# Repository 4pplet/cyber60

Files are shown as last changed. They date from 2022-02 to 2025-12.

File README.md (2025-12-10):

# cyber60

A DIY-friendly 60% using nRF52840 and ZMK: the cyber.

Verified compatibility list: [Link](./COMPAT.md)

## Note:
ALPS and SMK version of revision E are still untested and set as a pre-release. These should work, but I recommend using revision D until the design is fully verified and tested. 

## Availability:
As an option to DIY, I'll try and keep these available for purchase here: https://4pplet.com/ For DIY, the production files are avaliable in releases.

## Software:
- Link to zmk-fork: https://github.com/4pplet/zmk
- Link to zmk-config (uf2-files in actions): https://github.com/4pplet/zmk-config-4pplet

## Instructions:
- How to flash/update bootloader (this is needed to be able to flash firmware via USB): [Link](./instructions/BL_FLASH_INSTRUCTION.md)
- How to flash/update firmware using ZMK-config: [Link](./instructions/ZMK-config_steps.md)
- How to flash/update firmware using ZMK-repo (most difficult): [Link](./instructions/ZMK_steps.md)

Easiest for remapping is to use ZMK Studio: https://zmk.studio/ This requires no reflashing if you already use the latest default firmware.

## Specs cyber60:
- Module: Holyiot YJ-18010 for rev A-D, E73-2G4M08S1C for rev E
- Standard Tray Mount support (need battery cutout for internal battery)
- "rubber worm"-mount support (both bakeneko v1 and bakeneko v3). Case still need battery cutout or space for an internal battery.
- Lipo charger for single cell 3.7V li-po/li-ion batteries (recommended JST SH battery: https://www.upgradekeyboards.com/product/filament-power-batteries-ultra-thin-lipo/, if soldering JST PH, adafruit batteries work well, but make sure they are not too thick)
- RGB-led under Capslock for multi function indicator, not supported on SMK-version. (compatible led for rev A-D: https://www.aliexpress.com/item/1005003719602946.html)
- Four versions running the same FW-implementation. One MX, one MXHS, one ALPS, one SMK
- USB horizontal placement is classic GH60, same as GH60, plain60, voyager60 etc.
- (rev B and newer) Underglow for cozy glow
- (rev B and newer) Buzzer for indicator or sweet tunes
- (rev B and newer) Rotary encoder at right most posision in split backspace or off board (compatible encoder: https://www.aliexpress.com/item/1005001265188249.html)
- (rev B and newer) Reverse polarity protection for battery
- (rev E and newer) Arbitrary battery polarity

## Todo:
- Test and verify ALPS and SMK E1 release.
- Improve flash/update ZMK instruction and documentation.
- Improve ZMK Studio implementation.

# Layout support (non hotswap):
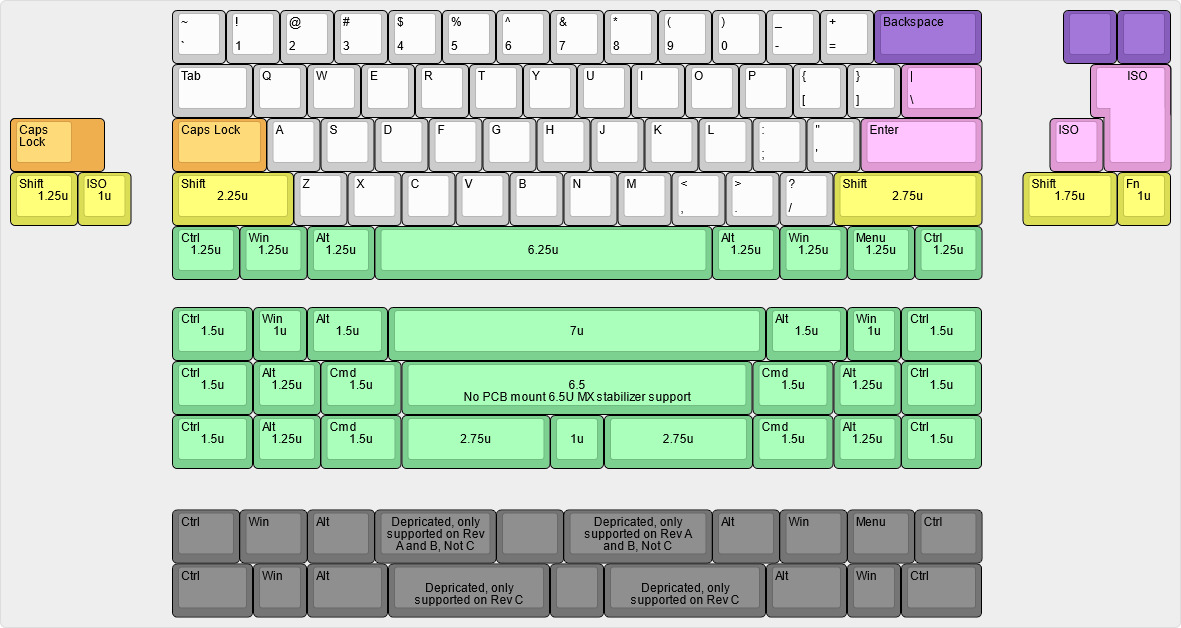
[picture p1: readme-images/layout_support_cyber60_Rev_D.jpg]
Layout support


# MX-version:
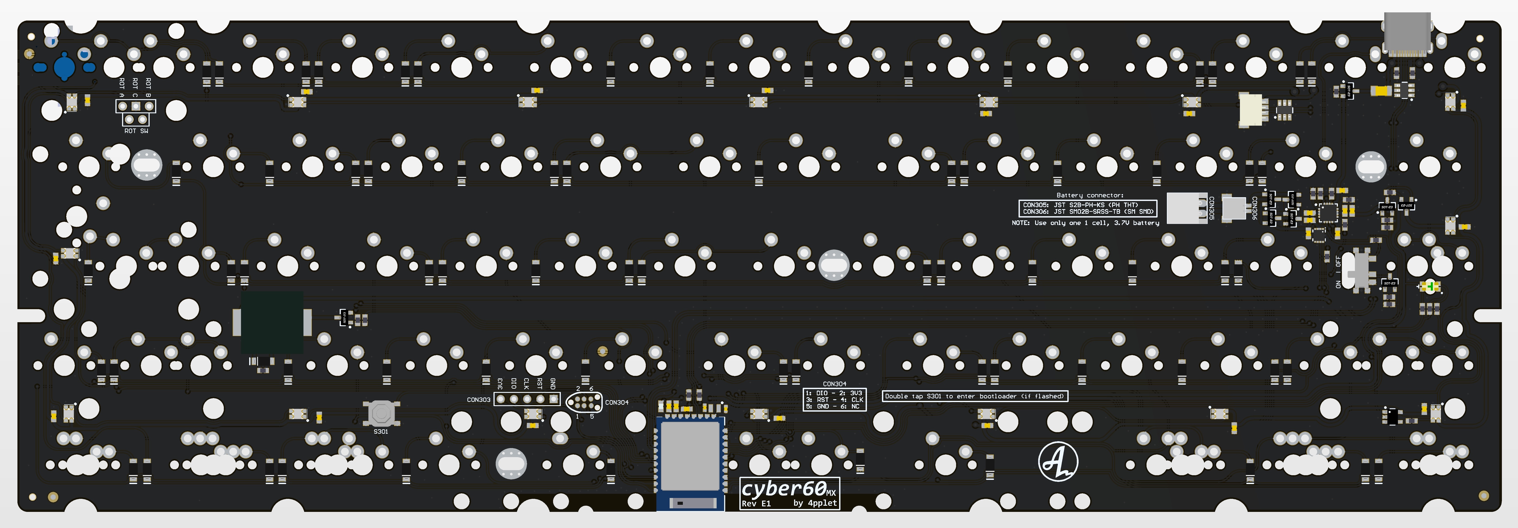
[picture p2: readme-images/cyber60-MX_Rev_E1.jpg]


## MX Revisions:
- A1 - initial revision/prototype
- A2 (prerelease) - flipped PMOS-transistor error in Rev A1. Added pulldown on enable to battery voltage measurement circuit, so it does not have to be disabled in code, only enabled. Minor silkscreen changes.
- B1 (prerelease) - Adding underglow, buzzer and rotary support. Simplifying voltage measurement circuit (tiny bit more leak current). Changing matrix to duplex.
- B2: Fixing underglow issue, adding n mos to fully turn off the p mos that powers the underglow. Adding reverse polarity protection for the battery.
- C1: Changing layout support for better solderability of module. Adding transistor cutoff for battery voltage measurement for no leak current. Switching to ws2812c in 2020-package. Rotating ANSI-enter stabilizer 180 degrees.
- C2: Minor adjustments to pads and soldermask
- D1: Removed 3U split space support, added 6.5u split into 2.75u + 1u + 2.75u.
- E1: Changed power curcuit (now high voltage mode), changed module, minor QOL changes

# ALPS-version
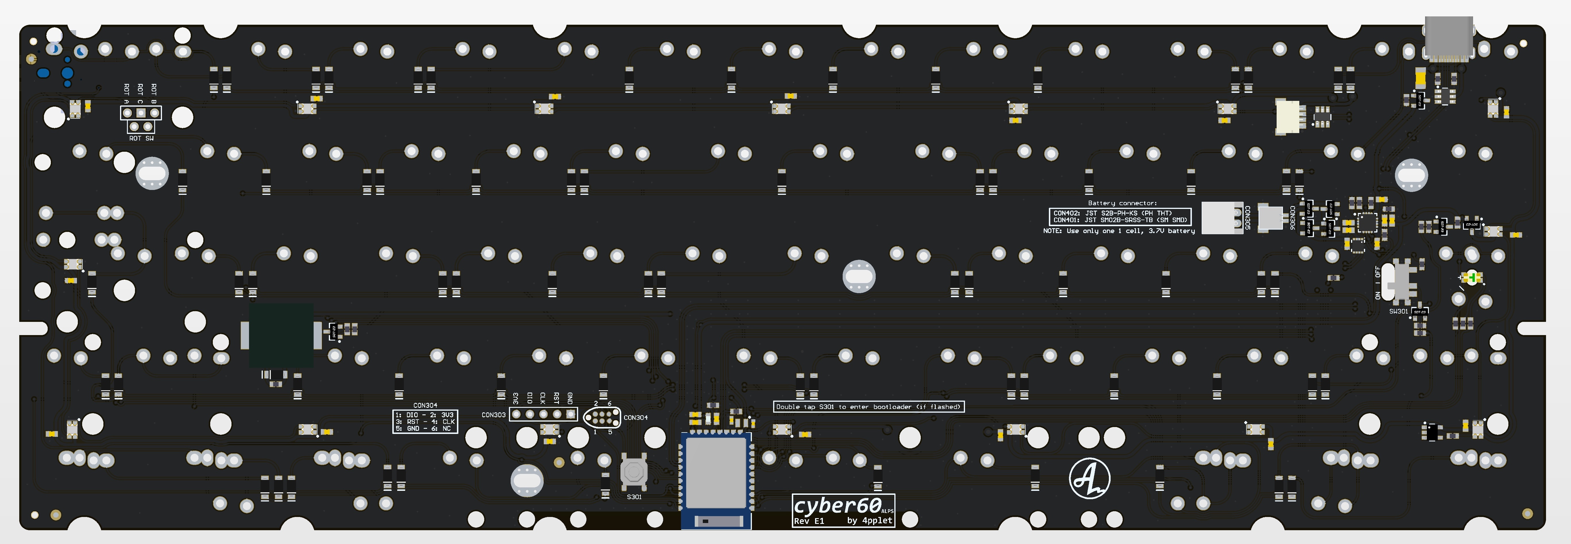
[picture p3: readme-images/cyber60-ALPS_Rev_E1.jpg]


## ALPS Revisions:
- A1 - initial revision/prototype, builds on MX rev A2
- B1 (prerelease) - Adding underglow, buzzer and rotary support. Simplifying voltage measurement circuit (tiny bit more leak current). Changing matrix to duplex.
- B2: Fixing underglow issue, adding n mos to fully turn off the p mos that powers the underglow. Adding reverse polarity protection for the battery.
- C1: Changing layout support for better solderability of module. Adding transistor cutoff for battery voltage measurement for no leak current. Switching to ws2812c in 2020-package. Rotating ANSI-enter stabilizer 180 degrees.
- C2: Minor adjustments to pads and soldermask
- D1: Removed 3U split space support
- E1: Changed power curcuit (now high voltage mode), changed module, minor QOL changes

# SMK-version
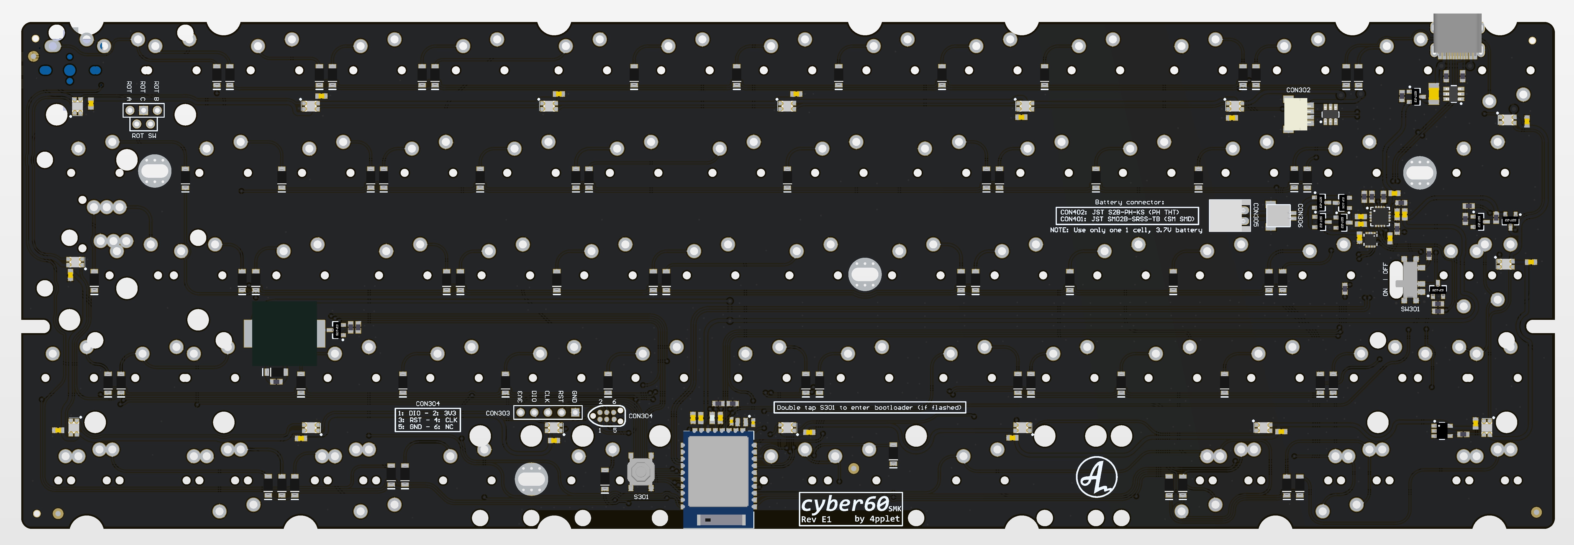
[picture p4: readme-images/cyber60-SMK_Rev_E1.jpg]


## SMK Revisions:
- A1: Initial revision/prototype, builds on ALPS rev A1
- B1: (prerelease) - Adding underglow, buzzer and rotary support. Simplifying voltage measurement circuit (tiny bit more leak current). Changing matrix to duplex.
- B2: Fixing underglow issue, adding n mos to fully turn off the p mos that powers the underglow. Adding reverse polarity protection for the battery.
- C1: Changing layout support for better solderability of module. Adding transistor cutoff for battery voltage measurement for no leak current. Switching to ws2812c in 2020-package. Rotating ANSI-enter stabilizer 180 degrees.
- C2: Minor adjustments to pads and soldermask
- D1: Removed 3U split space support
- D2: Fixed error in footprint for backspace keys.
- E1: Changed power curcuit (now high voltage mode), changed module, minor QOL changes

# MX Hot swap-version
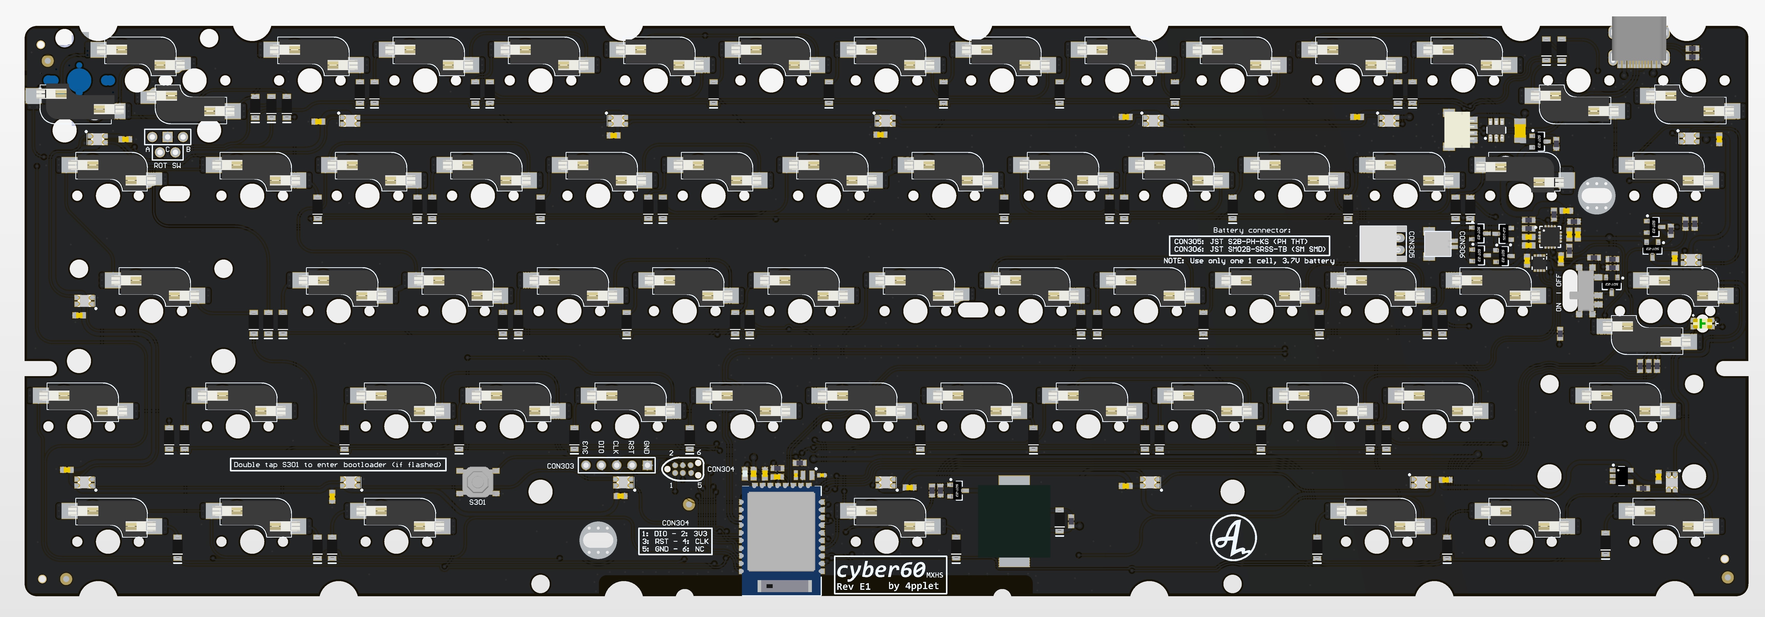
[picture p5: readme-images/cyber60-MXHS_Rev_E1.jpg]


## Layout support:
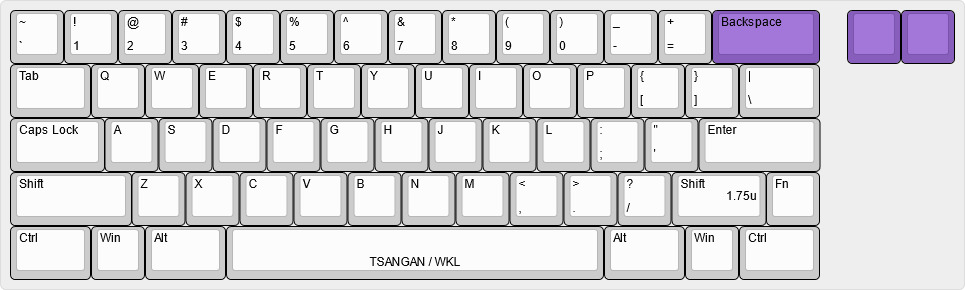
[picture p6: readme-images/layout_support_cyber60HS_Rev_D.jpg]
Layout support


## Default ZMK firmware:
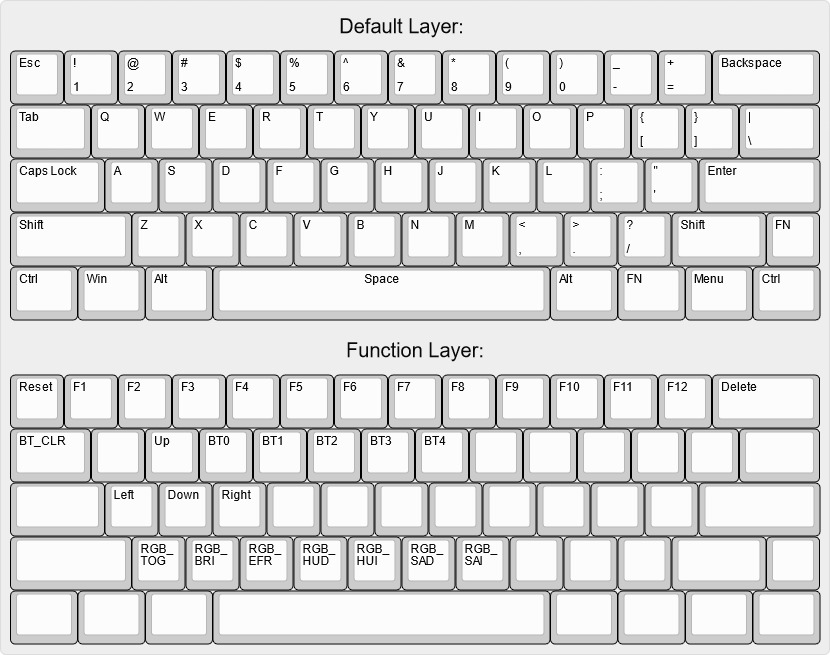
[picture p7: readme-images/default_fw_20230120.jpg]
Default firmware


## MXHS Revisions:
- C1: Initial revision, based on MX C1.
- C2: Minor adjustments to pads and soldermask
- D1: Removed 3U split space support
- D2: Changed to anti-shear footprints
- E1: Changed power curcuit (now high voltage mode), changed module, minor QOL changes

<a href='https://ko-fi.com/4pplet' target='_blank'>Buy Me a Coffee at ko-fi.com

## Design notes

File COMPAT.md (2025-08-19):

# Cyber60 - Compatibility list

## Compatible:
- **BBOX60** Minor modifications can be needed to the case. Used PCB: Cyber60 Rev D Solder
- **KBDFans Tofu V1**. Used PCB: Cyber60 Rev C Hot swap. Ample space for PCB and battery.
- **Bakeneko** Used PCB:  Cyber60 Rev D. Fit with the USB-C connector desoldered. A thin battery is required.

## Not fully compatible:
- **Unikorn R2** Will fit with the USB-C connector desoldered. Unikorn cases use a different daughterboard placment which can cause compatibility issues, use a longer daughterboard connector cable. Used PCB: Cyber60 Rev E. 25cm JST cable. Upgrade Keyboard Ultrathin LiPOs (1400mah)

## Incompatible:

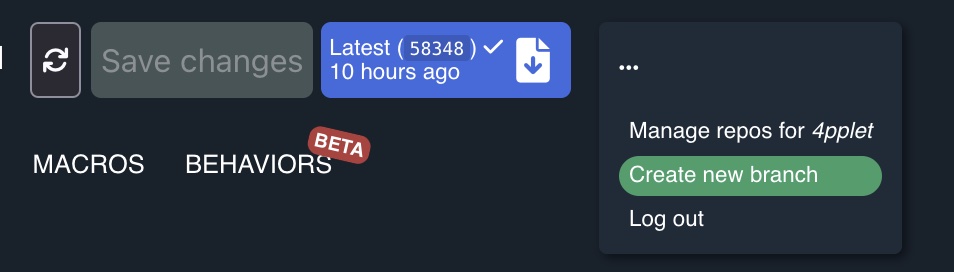
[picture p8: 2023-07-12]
readme-images/keymap-editor_branch.jpg

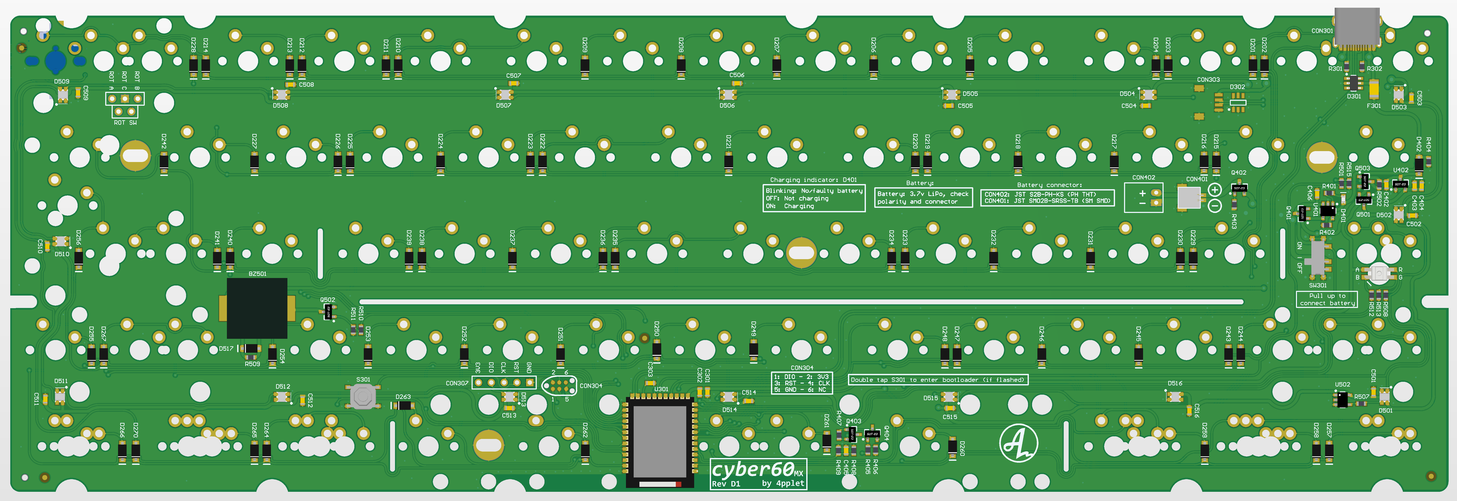
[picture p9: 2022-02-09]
readme-images/cyber60-MX_Rev_D1_Tray.png.png

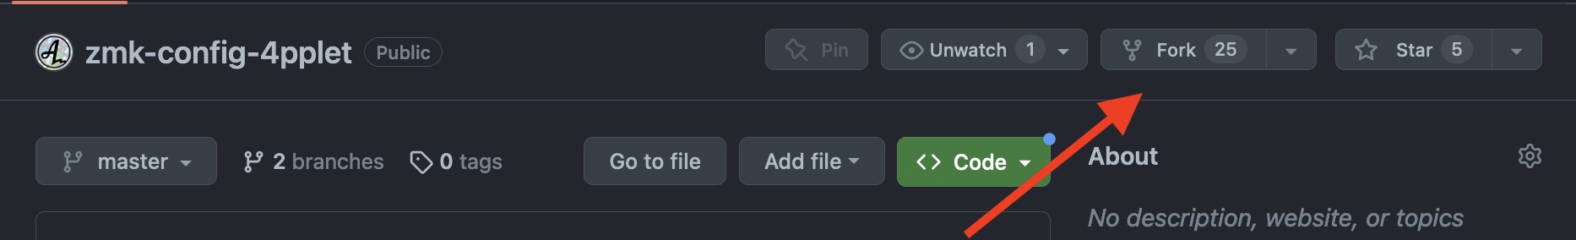
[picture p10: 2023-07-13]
readme-images/keymap-editor_fork.jpg

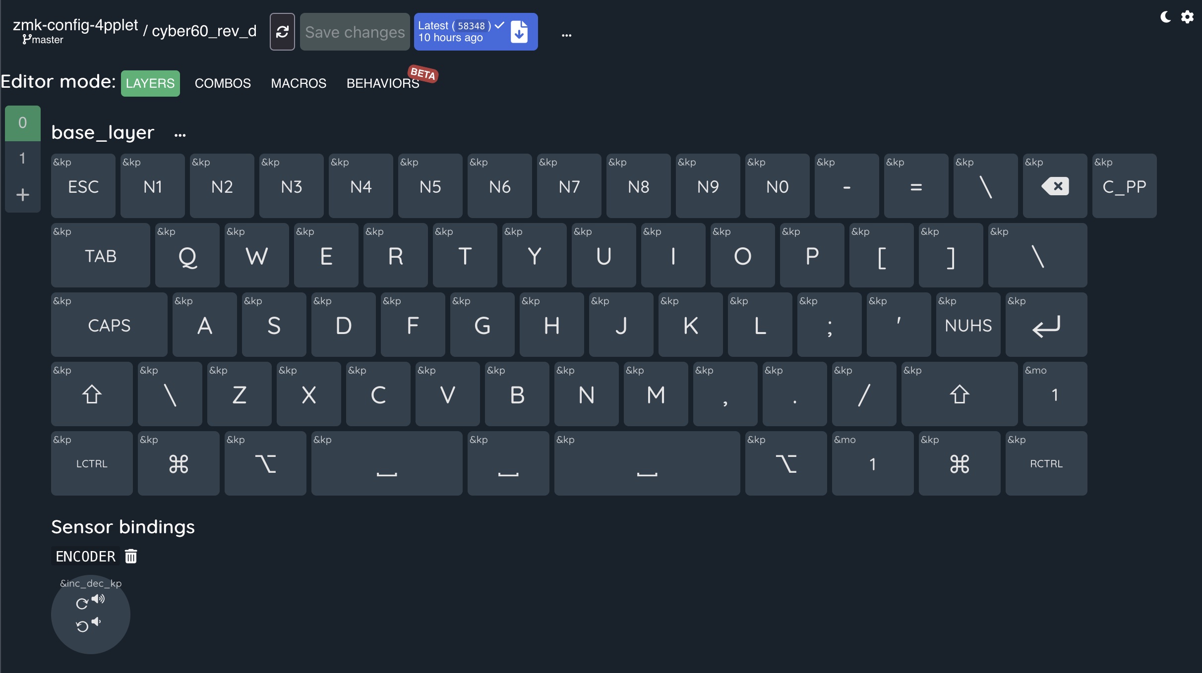
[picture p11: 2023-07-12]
readme-images/keymap-editor.jpg

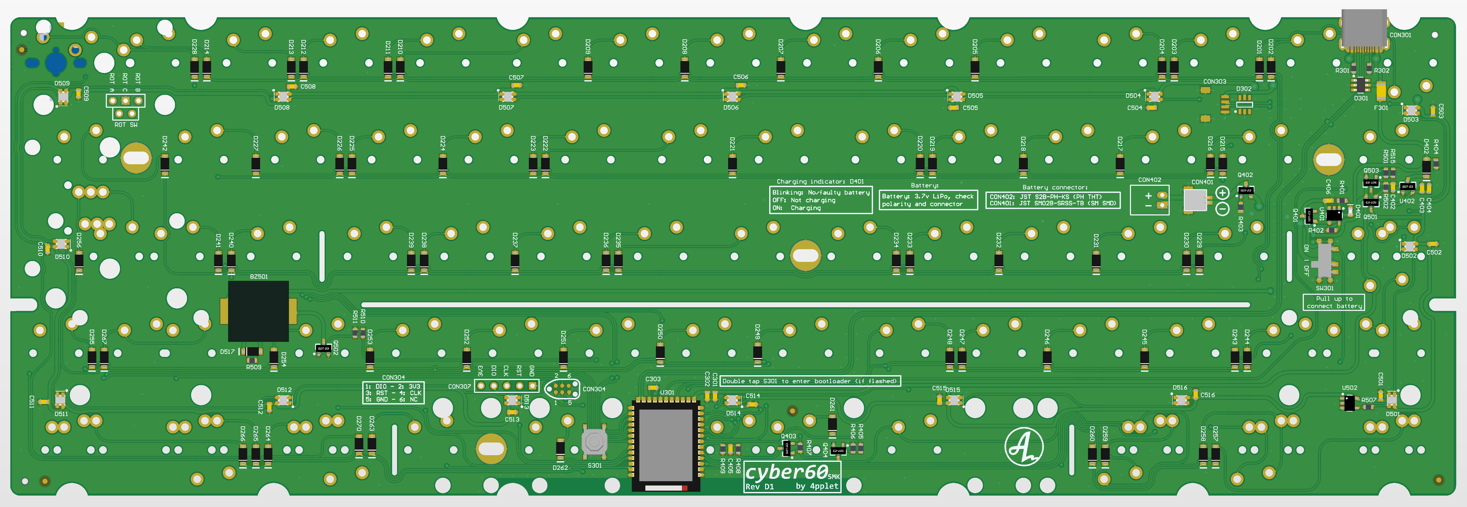
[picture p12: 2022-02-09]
readme-images/cyber60-SMK_Rev_D1_Tray.png

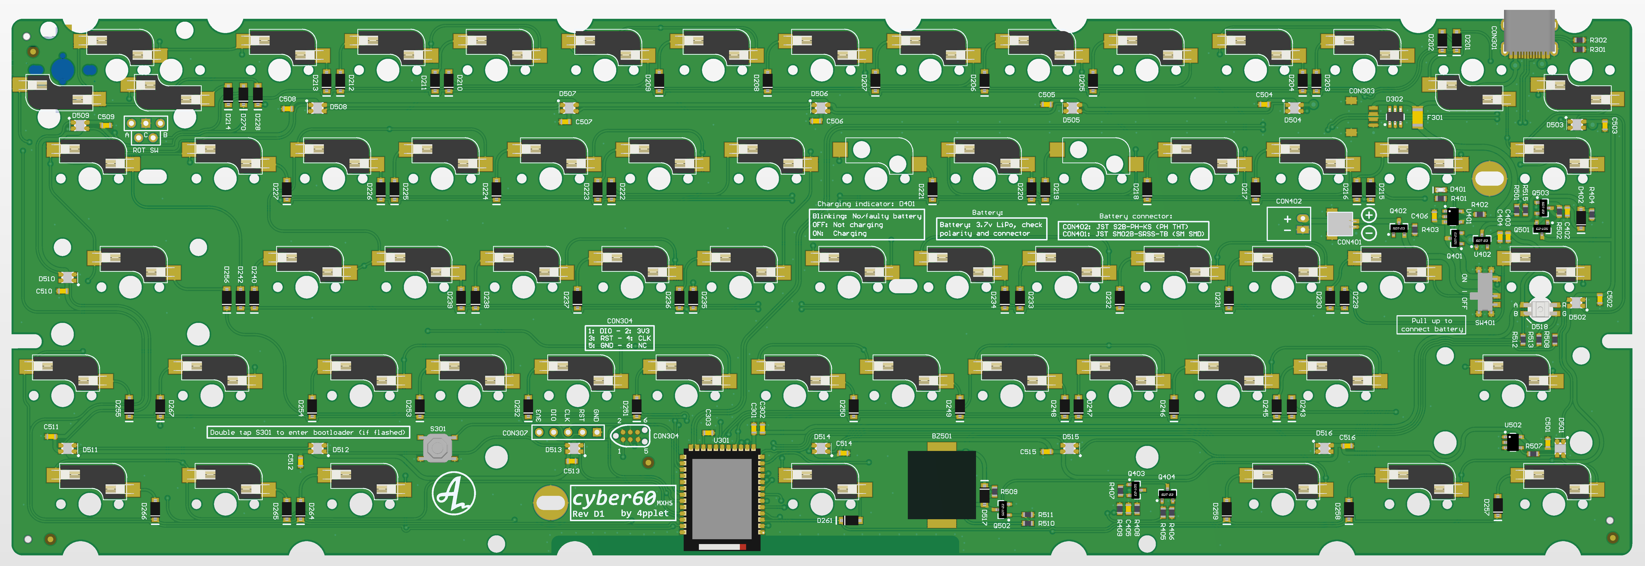
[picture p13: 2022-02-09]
readme-images/cyber60-MXHS_Rev_D1_Tray.png

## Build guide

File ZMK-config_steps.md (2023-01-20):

This is a short instruction on how to get started with editing the ZMK-config files and the usual steps required to flash the PCB. It's a work in progress, if you find it lacking, please do a PR with more info or create an issue with what you are missing. This is not a full instruction on how to edit and setup ZMK, for that, use the ZMK documentation: https://zmk.dev/docs

Note: Currently, the buzzer and RGB indicator LED do not work on the ZMK-config branch. You'll need to build locally.

## 1: Fork the ZMK-config repo
Open this URL in a browser and press the fork button, this requires a GitHub account: https://github.com/4pplet/zmk-config-4pplet
## 2: Get the code to your computer locally 
Clone the fork you just made so you have the files locally and can edit them. I'd recommend to use the github app. You can edit the files directly on GitHub, but it's harder to spot errors that way.
## 3: Make changes to the code and behavior
Make changes to your keymap or other behavior, note that you need to modify the files for the revision of the PCB that you use. If you are unsure, the revision is printed to the PCB. It's a letter and a number. The letter will indicate what revision you are on, for example B2 is revision B.
- Here is a good instruction on how to make keymap changes: https://zmk.dev/docs/features/keymaps
- The keymap files can be found in zmk-config -> config -> boards -> arm -> then the folder of the revision of the cyber60 you are using.
I'd recommend to use Visual studo code for this, but use a editor of your liking.
## 4: Push the code to GitHub
4: Push the code to your fork on GitHub
- The firmware will now build using GitHub actions and be available as a artifact called "firmware"
## 5: Locate the build in GitHub actions
Open the github actions tab and click on your commit
- If the changes you made are correct/working, there should be green check marks.
## 6: Download firmware
In the "Artifacts section", click firmware and you'll download a zip-file containing the compiled firmware.
## 7: Unpack the zip
Unpack this zip-file and you'll have the built firmware for all the different revisions. Note that you need to use the one built for the revision you edited.
## 8: Set the PCB in reprogram mode (enter uf2 bootloader)
On the PCB, double click on the reset-button and it'll show up on your PC as a removable device.
## 9: Flash your edited firmware
To reflash the PCB, copy the generated .uf2 file from the unpacked .zip file into the removable device (or drag drop) and the PCB will be re-flashed with your modified changes.

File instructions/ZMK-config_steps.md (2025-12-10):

This is a short instruction on how to get started with editing the ZMK-config files and the usual steps required to flash the PCB. It's a work in progress, if you find it lacking, please do a PR with more info or create an issue with what you are missing. This is not a full instruction on how to edit and setup ZMK, for that, use the ZMK documentation: https://zmk.dev/docs

## 0: (prerequisite) for github
Create a github account and log in to it.
## 1: Fork the ZMK-config repo
Open this URL in a browser and press the fork button, this requires a GitHub account: https://github.com/4pplet/zmk-config-4pplet
## 2: Get the code to your computer locally
Clone the fork you just made so you have the files locally and can edit them. I'd recommend to use the github app. You can edit the files directly on GitHub, but it's harder to spot errors that way.
## 3: Make changes to the code and behavior
Make changes to your keymap or other behavior, note that you need to modify the files for the revision of the PCB that you use. If you are unsure, the revision is printed to the PCB. It's a letter and a number. The letter will indicate what revision you are on, for example E1 is revision E.
- Here is a good instruction on how to make keymap changes: https://zmk.dev/docs/features/keymaps
- The keymap files can be found in `zmk-config/config/` (e.g. `cyber60_rev_e.keymap`)
I'd recommend to use Visual Studio Code for this, but use an editor of your liking.
## 4: Push the code to GitHub
Push the code to your fork on GitHub.
- The firmware will now build using GitHub actions and be available as an artifact called "firmware"
## 5: Locate the build in GitHub actions
Open the GitHub Actions tab and click on your commit.
- If the changes you made are correct/working, there should be green check marks.
## 6: Download firmware
In the "Artifacts" section, click firmware and you'll download a zip-file containing the compiled firmware.
## 7: Unpack the zip
Unpack this zip-file and you'll have the built firmware for all the different revisions. Note that you need to use the one built for the revision you edited.
## 8: Set the PCB in reprogram mode (enter uf2 bootloader)
To flash the built firmware, the PCB needs to be put in reprogram/bootloader mode. With the default keymap, this can be done by pressing Fn + CapsLock. Alternatively, you can double click on the reset button on the PCB. When the keyboard enters this mode, key input will no longer work and a UF2 removable device will show up on your PC.
## 9: Flash your edited firmware
To reflash the PCB, copy the generated .uf2 file from the unpacked .zip file into the removable device (or drag drop) and the PCB will be re-flashed with your modified changes.

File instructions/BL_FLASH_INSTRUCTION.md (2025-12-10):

# Cyber60 Bootloader Flash Instructions

I recommend using a **J-Link** programmer to flash the bootloader. If you want to use another programmer, I suggest checking out Joric’s wiki for instructions:  
https://github.com/joric/nrfmicro/wiki/Bootloader

---

## TL;DR:
- Follow **Step 2** in this guide:  
  https://learn.adafruit.com/bluefruit-nrf52-feather-learning-guide/flashing-the-bootloader
- **BUT** use the bootloader from here instead:  
  https://github.com/4pplet/Adafruit_nRF52_Bootloader/releases

If your PCB already has the bootloader flashed (either from the factory or previously), you can update it by dragging the **UF2 update file** from the release.  
Be sure to use the correct update file for your **PCB revision**.

---

## Mac / Linux:

1. Install `nrfjprog` (via [nRF Command Line Tools](https://www.nordicsemi.com/Products/Development-tools/nRF-Command-Line-Tools/Download))
2. Download the bootloader (`.hex` file):  
   https://github.com/4pplet/Adafruit_nRF52_Bootloader/releases  
   Make sure it matches your Cyber60 revision.  
   Revisions **A** and **B** use the same bootloader.  
   Look for the letter under the "cyber60" name on the PCB.
3. Open a terminal and navigate to the bootloader directory.
4. Connect power to the PCB (USB or battery), and connect your programmer (via tag-connect or 2.54 header).
5. Flash using:
   ```bash
   nrfjprog --program [bootloader_name].hex --chiperase -f nrf52 --verify --reset
   ```
6. If you get a "device is locked" error:
   ```bash
   nrfjprog --recover
   ```
   Then retry the flashing command.

### Expected success output:
```
[ #################### ]   0.218s | Erase file - Done erasing
[ #################### ]   1.293s | Program file - Done programming
[ #################### ]   1.337s | Verify file - Done verifying
Applying system reset.
Run.
```

7. If successful, your PCB should show up as a USB drive named `CYBER_<Revision>`.  
   If it doesn’t, try:
   - Unplugging and replugging USB + battery  
   - Double-clicking the reset button to enter bootloader mode

---

## Windows:

1. Install [nRF Command Line Tools](https://www.nordicsemi.com/Products/Development-tools/nrf-command-line-tools/download)
2. Install [J-Link drivers](https://www.segger.com/downloads/jlink/)
3. Download the appropriate bootloader `.hex` file from:  
   https://github.com/4pplet/Adafruit_nRF52_Bootloader/releases  
   Again: use the version that matches your PCB revision.
4. Either:
   - Copy the bootloader to your `nrf-command-line-tools` folder (e.g. `C:\Program Files (x86)\Nordic Semiconductor\nrf-command-line-tools\bin\`)  
   - OR copy `nrfjprog.exe` into the folder where the `.hex` file is
5. Open Command Prompt
6. Navigate to the correct directory
7. Connect USB/power to the PCB and attach your programmer
8. Run:
   ```cmd
   nrfjprog.exe --program [bootloader_name].hex --chiperase -f nrf52 --verify --reset
   ```
9. If you get a "device is locked" error:
   ```cmd
   nrfjprog.exe --recover
   ```
   Then retry the flashing command.

### Expected success output:
```
[ #################### ]   0.218s | Erase file - Done erasing
[ #################### ]   1.293s | Program file - Done programming
[ #################### ]   1.337s | Verify file - Done verifying
Applying system reset.
Run.
```

10. If all goes well, you should see a removable device named `CYBER_<Revision>`.  
    If not:
    - Unplug USB and battery, then reconnect
    - Double-tap the reset button to enter bootloader mode

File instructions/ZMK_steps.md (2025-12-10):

This is a short instruction on how to get started with building ZMK locally. It's a work in progress, if you find it lacking, please do a PR with more info or create an issue with what you are missing. This is not a full instruction on how to edit and setup ZMK, for that, use the ZMK documentation: https://zmk.dev/docs

## 1: Fork the ZMK repo
Open this URL in a browser and press the fork button, this requires a GitHub account: https://github.com/4pplet/zmk
## 2: Get the code to your computer locally
Clone the fork you just made so you have the files locally and can edit them. I'd recommend to use the github app. You can edit the files directly on GitHub, but it's harder to spot errors that way.
## 3: Make changes to the code and behavior
Make changes to your keymap or other behavior, note that you need to modify the files for the revision of the PCB that you use. If you are unsure, the revision is printed to the PCB. It's a letter and a number. The letter will indicate what revision you are on, for example B2 is revision B.
- Here is a good instruction on how to make keymap changes: https://zmk.dev/docs/features/keymaps
- The keymap files can be found in `zmk/app/boards/4pplet/cyber60/` (e.g. `cyber60_rev_e.keymap`)
I'd recommend to use Visual Studio Code for this, but use an editor of your liking.
## 4: Install ZMK toolchain
Follow the instructions by ZMK to install the toolchain, I highly recommend to use the docker setup.
https://zmk.dev/docs/development/setup
## 5: Build ZMK
In the terminal, navigate to the ZMK directory that was cloned from GitHub in step 2.
Change folder to app:
```bash
cd app
```

Build ZMK, replace the revision letter depending on what revision you are building:
```bash
west build -p -b cyber60@rev_e
```

Available revisions: `rev_a`, `rev_b`, `rev_c`, `rev_d`, `rev_e`

## 6: Locate the built .uf2
The file will be called `zmk.uf2` and located in `zmk/app/build/zephyr/`
## 7: Set the PCB in reprogram mode (enter uf2 bootloader)
To flash the built firmware, the PCB needs to be put in reprogram/bootloader mode. With the default keymap, this can be done by pressing Fn + CapsLock. Alternatively, you can double click on the reset button on the PCB. When the keyboard enters this mode, key input will no longer work and a UF2 removable device will show up on your PC.
## 8: Flash your edited firmware
To reflash the PCB, copy the generated zmk.uf2 file into the removable device (or drag drop) and the PCB will be re-flashed with your modified changes.

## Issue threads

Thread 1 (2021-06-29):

Solder mask

mannahusum, 2021-06-29:
I really appreciate your work. I’m on my way to build a keyboard, my first, with your design.

PCBway complained about drilling away a via, if I get it right:

As shown in attached screenshots, the soldermask opening on the GTS layer is larger than pads on the GTL layer. But some of the soldermask opening on the GBS layer is smaller than pads on the GBL layer, so could you enlarge the soldermask opening 2mil around these pads like the soldermask opening on the GTS layer?

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

I don’t have the software to create and offer a fix, though

4pplet, 2021-07-05:
Hi!

Thanks for showing interest in the project! Sorry for the delayed response.

I'll see if I can sort it out. If I get this right, they are concerned about that the soldermask covers the pad on one side if the PCB? It is done like this on purpose, so that the pad is not visible on the side you place the switches. It is not an issue. :)

What VIA are they complaining about?

Closed 2021-08-24.

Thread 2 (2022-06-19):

led per key

Davides98, 2022-06-19:
Hi,
Can you implement rgb led per keys?

I have seen that two types of LEDs are available :
-LED addresable (sk6812 e-mini)
-LED matrix

The latter of these should have a lower power consumption

4pplet, 2022-09-16:
No plans to add per key leds at the moment, we'll see for future revisions :) If added, it'll be LED matrix

Closed 2022-09-16.

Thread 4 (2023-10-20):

Very high battery drain?

pseudobacon, 2023-10-20:
I built my own cyber60 mxhs version and have firmware compiled from July 23 2023 and seem to be having very high battery drain. I am using a 1460mah battery which I have used in a similar keyboard with a nRF52810 chip - [GT-BLE60](https://github.com/genokolar/Lotkb_Keyboard_PCB) and the keyboard will only last maybe 2-3 days maximum. On my other bluetooth keyboard I am able to get months of battery life.

I'm looking to see if there is a way to diagnose this drain either in software or hardware?

4pplet, 2023-11-04:
I would suspect a short somewhere, since the battery drain is very high. Are all functions working?

pseudobacon, 2023-11-08:
As far as I'm aware, all functions are working. The battery charges and discharges of course, all the keys are working on the keyboard. I've remapped a couple of keys from the default layout as well, including swapping the rotary encoder volume up and down behaviour back to what it was and that seems fine. I have it paired with two different devices, and swapping them is also fine too.

4pplet, 2023-11-16:
It's really hard for me to tell. I'd still suggest looking for shorts. Also make sure the transistor that shuts of underglow when not active works for example.

pseudobacon, 2024-01-11:
Hmm well the undergrow toggle is working, all LEDs turn on and off as expected. I'll see if I can get my hands on a thermal camera

Closed 2024-01-11.

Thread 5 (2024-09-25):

Case compatibility list?

cfergeau, 2024-09-25:
A list of compatible cases similar to https://docs.google.com/spreadsheets/u/2/d/13Lbbcl5IB17AtRAp6NcSjG65x_7uYAqBwbp5UiGhyJw/htmlview# would be useful to have.
I've seen mentions of the tofu60, the bakeneko, the frog mini, and maybe the unikorn, I don't know if there are others where the PCB is known to fit (or not to fit :)

4pplet, 2024-09-26:
Thanks for suggesting this!

I have started on a compatibility list. If anyone have more input re. usage of cases, please make a PR and add info or drop me a email/PM.

https://github.com/4pplet/cyber60/blob/master/COMPAT.md

Closed 2024-09-26.

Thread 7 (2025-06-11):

64-key MX Hotswap Layout

UnchartedBull, 2025-06-11:
Really like the project and it seems like the perfect fit to finally move all my keyboards over to ZMK. I just have one issue - I'm using the not super common 64 key layout for 60% (2U shift, with a slightly shifted 4th row & 5 keys on the right of the 5th row). This allows accommodation of arrow key while keeping the 60% layout and it's a perfect fit for me.

I don't have an Altium Designer License and KiCad is really unhappy with importing the design files (multiple footprints missing, which makes it nearly impossible to make changes to the board). So my question would be if you'd be willing to do a 64 key hotswap MX layout. I'm willing to buy you a couple of coffees if you can accommodate that :). I just need the changed PCB files, ZMK config and such I can create on my own and then provide via a PR to this repo.

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

If you can't do that please let me know so I can further investigate on how to best edit these files with KiCad.

Thanks!
Timon

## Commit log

2020-06-08 started rough layout, module not added yet
    [BLE-T1.PcbDoc]
2020-06-08 minor changes, still a mess
    [BLE-T1.PcbDoc, BLE-T1.PrjPcb]
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2020-06-10 changed power solution to be more like adafruit feather
    [1_BLE-T1_top.SchDoc, 3_BLE-T1-mcu.SchDoc, 4_BLE-T1_power.SchDoc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]
2020-06-11 DRC OK, need to fix gnd for antenna
    [1_BLE-T1_top.SchDoc, 3_BLE-T1-mcu.SchDoc, BLE-T1.PrjPcb]
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2020-06-14 changed matrix to get one extra pin, added swo
    changed matrix to get one extra pin, added swo
    [1_BLE-T1_top.SchDoc, 2_BLE-T1-matrix.SchDoc, 3_BLE-T1-mcu.SchDoc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]
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2020-06-16 added smaller JST connector for battery, moved stuff around
    added smaller JST connector for battery, moved stuff around
    [4_BLE-T1_power.SchDoc]
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2020-07-08 added other BLE project
    [1_BLE-T2_top.SchDoc, 2_BLE-T2_matrix.SchDoc, 3_BLE-T2_mcu.SchDoc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]
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2020-07-08 Moved JST connector down a bit
    [BLE-T1.PrjPcb]
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2020-09-07 initial commit of T3 before starting to change BT-module
    [1_BLE-T3_top.SchDoc, 2_BLE-T3-matrix.SchDoc, 3_BLE-T3-mcu.SchDoc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]
2020-09-08 started implementing compact matrix
    [2_BLE-T3-matrix.SchDoc]
2020-09-09 DRC OK, still stuff to double check on schematic-side
    [1_BLE-T3_top.SchDoc, 3_BLE-T3-mcu.SchDoc]
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2020-09-10 DRC Check on all 3 OK
    [BLE-T1.PrjPcb, BLE-T2.PrjPcb]
2020-09-15 cont, still fixing with matrix and ISO enter
    [2_BLE-T1-matrix.SchDoc, 2_BLE-T2_matrix.SchDoc, 2_BLE-T3-matrix.SchDoc]
2020-09-21 done with enter matrix move
    [2_BLE-T2_matrix.SchDoc]
2020-09-28 Fixed regulator pinout
    [3_BLE-T2_mcu.SchDoc, 4_BLE-T1_power.SchDoc, 4_BLE-T3_power.SchDoc]
2020-09-28 added diodes for battery charger status
    [1_BLE-T3_top.SchDoc, 3_BLE-T3-mcu.SchDoc, 4_BLE-T1_power.SchDoc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]
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2020-10-07 updated to shottky-diodes for power
    [3_BLE-T1-mcu.SchDoc, 3_BLE-T2_mcu.SchDoc, 3_BLE-T3-mcu.SchDoc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]
2020-10-08 cleaned up paramters a bit
    [2_BLE-T1-matrix.SchDoc, 3_BLE-T1-mcu.SchDoc, 3_BLE-T2_mcu.SchDoc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]
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2020-10-13 fixed assembly-drawing layer
2020-10-13 minor assembly drawing fixes
2020-10-13 DRC OK on both projects
    [cyber60-1.PrjPcb, cyber60-2.PrjPcb]
2020-10-14 updated gnd pour, replaced battery switch and updated battery footprint
    updated gnd pour, replaced battery switch and updated battery footprint
    [3_cyber60-1_mcu.SchDoc, 4_cyber60-2_power.SchDoc]
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2020-11-02 added direction indicator for RGB-led
    [cyber60-2.PrjPcb]
2020-11-10 removed cyber-1 for now. Focus will be cyber-2 version
    [1_cyber60-1_top.SchDoc, 2_cyber60-1_matrix.SchDoc, 3_cyber60-1_mcu.SchDoc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]
2020-11-15 fixed mirrored transistor. Added pulldown and removed series resistor on vbat enable.
    fixed mirrored transistor. Added pulldown and removed series resistor on vbat enable.
    [3_cyber60-2-mcu.SchDoc]
2020-11-15 added reset switch footprint to top-side. Changed switch footprint to only jlc-basic reset switch
    added reset switch footprint to top-side. Changed switch footprint to only jlc-basic reset switch
    [3_cyber60-2-mcu.SchDoc]
2020-11-15 fixed assembly-drawing for new reset switch
2020-11-19 reverted movement of reset button, added text to show battery on/off
2020-11-19 updated resistances so we cant exceed max gpio source or drain-current
    [3_cyber60-2-mcu.SchDoc]
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2020-11-21 started playing with a alps PCB
    [1_cyber60-2_top.SchDoc, 1_cyber60-alps_top.SchDoc, 1_cyber60_top.SchDoc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]
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2020-11-24 restoring LED on alps version
    [3_cyber60-alps_mcu.SchDoc]
2020-11-27 initial commit of SMK version before starting to change stuff, based on alps project
    initial commit of SMK version before starting to change stuff, based on alps project
    [1_cyber60-smk_top.SchDoc, 2_cyber60-smk_matrix.SchDoc, 3_cyber60-smk_mcu.SchDoc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]
2020-11-27 cont changing footprints to SMK
    [2_cyber60-smk_matrix.SchDoc, cyber60-smk.PrjPcb]
2020-11-28 fixed layout support on alps. cont changing footprints on SMK
    fixed layout support on alps. cont changing footprints on SMK
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2020-11-29 removed incorrect component designator in schematic
    [4_cyber60-alps_power.SchDoc, 4_cyber60-smk_power.SchDoc]
2020-11-29 updated mx-file naming. moved battery connectors up 1mm so all projects allign (SMK version needed it)
    [1_cyber60-mx_top.SchDoc, 1_cyber60_top.SchDoc, 2_cyber60-matrix.SchDoc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]
2020-12-01 updated vbus sensing to be behind the diode
    [2_cyber60-alps_matrix.SchDoc, 3_cyber60-alps_mcu.SchDoc, 3_cyber60-mx_mcu.SchDoc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]
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2021-01-19 fixed mfg and pn for underglow leds.
    [5_cyber60-mx_periferals.SchDoc]
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2021-02-01 updated capslock led footprint
    updated capslock led footprint
    [cyber60-alps.PrjPcb, cyber60-mx.PrjPcb, cyber60-smk.PrjPcb]
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2021-02-10 Fixed error on silkscreen
2021-03-07 updated rotary footprint, added reverse voltage proection for battery, updated flex
    updated rotary footprint, added reverse voltage proection for battery, updated flex
    [4_cyber60-alps_power.SchDoc, 4_cyber60-mx_power.SchDoc, 4_cyber60-smk_power.SchDoc]
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2021-03-20 adding nmos to properly close underglow pmos transistor
    [5_cyber60-alps_periferals.SchDoc, 5_cyber60-mx_periferals.SchDoc, 5_cyber60-smk_periferals.SchDoc]
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2021-04-20 added missing info on battery switch for PCBA
    added missing info on battery switch for PCBA
    [4_cyber60-alps_power.SchDoc, 4_cyber60-mx_power.SchDoc, 4_cyber60-smk_power.SchDoc]
2021-07-08 fixed outline
    [cyber60-smk.PrjPcb]
2021-07-19 restored correct project files.
    [1_cyber60-mx_top.SchDoc, 2_cyber60-alps_matrix.SchDoc, 2_cyber60-mx-matrix.SchDoc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]
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2021-09-02 files generated for prerelease. Project cleaned up a bit
    [cyber60-alps-bkplate.PcbDoc, cyber60-alps.PrjPcb, cyber60-mx-bkplate.PcbDoc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]
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2021-10-29 added missing tooling hole for JLC
    [cyber60-mxhs.PrjPcb]
2021-11-10 starting on rev C2 - minor fixes and tweaks
    [3_cyber60-alps_mcu.SchDoc, 4_cyber60-alps_power.SchDoc, 4_cyber60-mx_power.SchDoc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]
2021-11-18 adding more rotation info for RGB-led and Buzzer
2022-02-09 Squashed commit of the following:
    commit 6b50d3800b2dfa038b9c979a8c34db0e064c233c
    Author: 4pplet <mail@4pplet.com>
    Date: Wed Feb 9 13:42:44 2022 +0100
    adding layout pics
    commit 55b06160f1154a3bd41593fae8488347657f235c
    Author: 4pplet <mail@4pplet.com>
    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
    [1_cyber60-mx_top.SchDoc, 1_cyber60-mxhs_top.SchDoc, 1_cyber60-smk_top.SchDoc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]
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2022-05-11 Squashed commit of the following:
    commit 127047330b25005206919843bbf9f1bfaf7e3410
    Merge: f10b3ee a02f15a
    Date: Wed May 11 21:49:10 2022 +0200
    Merge branch 'master' into dev
    commit f10b3ee6536ac42c17a201fe8d9468dd7a45efec
    Date: Wed May 11 21:48:57 2022 +0200
    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
    [1_cyber60-smk_top.SchDoc, 2_cyber60-mxhs_matrix.SchDoc, 2_cyber60-smk_matrix.SchDoc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]
2022-08-22 update info for hotswap sockets and added to BOM
    [2_cyber60-mxhs_matrix.SchDoc, cyber60-mxhs.PrjPcb]
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2025-05-09 Squashed commit of the following:
    commit 283133303d6af104f573cd23d7d0aa6e763dcf74
    Date: Thu May 8 22:12:40 2025 +0200
    cont
    commit d54b7621c360808845e673f05f5fb3eb4e7b9420
    Date: Thu May 8 22:07:13 2025 +0200
    cont
    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
    [1_cyber60-alps_top.SchDoc, 1_cyber60-mx_top.SchDoc, 1_cyber60-mxhs_top.SchDoc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]
